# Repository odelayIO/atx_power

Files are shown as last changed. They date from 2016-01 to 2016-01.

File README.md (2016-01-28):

# 15 Port USB Power Supply using an ATX Power Supply
<br>
##### View on [gh-page](http://odelayio.github.io/atx_power/)

## Problem Statement
I’m continuously using all of my wall outlets to plug-in a USB wall wart power supply to use for all of my development boards (e.g. Raspberry Pi, Arduino, etc).  Over time I needed two 6 port power strips just to have enough outlets for the USB wall wart.  To address this issue, I designed a very simple 15 Power USB power supply using an ATX Power Supply.

## Introduction
This design is a passive USB power supply, meaning this design directly connects the ATX Power Supply +5DCV directly to the +5DCV pin of a USB connector.  I was considering adding a USB charging port controller and current limiting power switch such as the [TSP2511](http://www.ti.com/product/TPS2511).  But I wanted to keep this design simple.

## Parts List
| Name | Description | Distrubutor | Price | URL |
|---|---|---|---|---|
| USB Connector | 3 Stack USB | Mouser | $4.24 | [Link](http://www.mouser.com/Search/ProductDetail.aspx?R=33UBAR-TSN1Rvirtualkey63110000virtualkey706-33UBAR-TSN1) |
| Binding Post  | For the power supply | Sparkfun | $0.35 | [Link](https://www.sparkfun.com/products/9739) |
| Fuse Holder | Fuse Clip 5mm | Sparkfun | $0.25 | [Link](https://www.sparkfun.com/products/9773) |
| PCB | 15 Port USB | DirtyPCBs | $25 | [Link](https://dirtypcbs.com) |

## Assembly

<br>
<br>
######PCB Layout Design
<br>
PCB
---
<br>
######I had an old ATX Power Supply, so I just used this one.  This ATX Power Supply cost around $15 on Amazon.com
<br>
Step 1

---
<br>
######This is the ATX Power Supply with the cover off.  As you can see, there is room in this ATX Power Supply to fit the PCB.
<br>
Step 2

---
<br>
######This design doesn't use an ATX connect to save money on the BOM. So I trimmed the wires to the desired length.
<br>
Step 3

---
<br>
######Solder the ATX wires to the designated power rail of the PCB.  The voltage is labeled on the silkscreen.
<br>
Step 4

---
<br>
######Modified the ATX Power Supply, so the PCB can be mounted
<br>
Step 5

---
<br>
######Fully assembled 15 Port USB Power Supply.  
<br>
Step 6

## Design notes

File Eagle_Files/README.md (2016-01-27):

# Eagle 7.3.0 Design Files

## File Description

- ATX_Power_Supply.sch : Schematic File
- ATX_Power_Supply.brd : Layout File
- ATX_Power_Supply_Gerber274_Final_17NOV2015.zip : Submitted Gerber Files
  - Boards have been fab at http://dirtypcbs.com/

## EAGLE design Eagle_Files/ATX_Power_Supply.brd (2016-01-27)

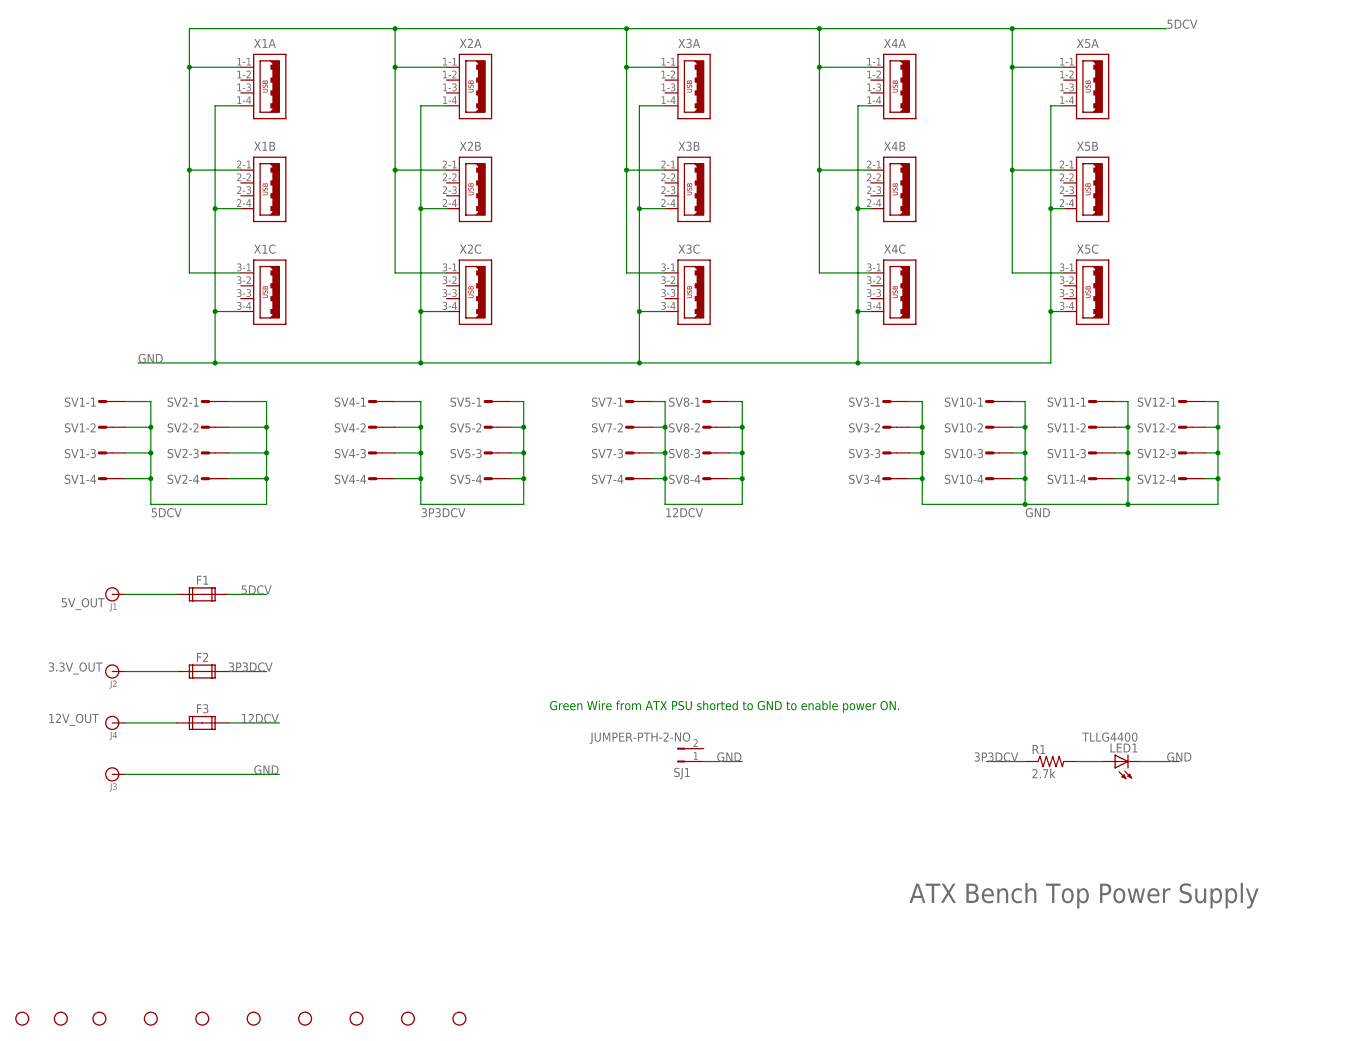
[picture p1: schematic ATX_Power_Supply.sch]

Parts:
F1, F2, F3: FUSE2P; FUSE1
J1, J2, J3, J4: BANANA_CONN
LED1: TLLG4400; LED3MM
R1: 2.7k; 0204/5
SJ1: JUMPER-PTH-2-NO; PTH-JUMPER-2-NO_NO_SILK
STANDOFF1, STANDOFF2, STANDOFF3, STANDOFF4, STANDOFF5, STANDOFF6, STANDOFF7, STANDOFF8, STANDOFF9, STANDOFF10: STAND-OFF
SV1, SV2, SV3, SV4, SV5, SV7, SV8, SV10, SV11, SV12: MT6-4
X1, X2, X3, X4, X5: USB_3PSHIELD-85-32003-00X-1; 85-32003-00X-1

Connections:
3.3V_OUT: F2.1A, J2.P$1
3P3DCV: F2.2A, R1.1, SV4.1, SV4.2, SV4.3, SV4.4, SV5.1, SV5.2, SV5.3, SV5.4
5DCV: F1.2A, SV1.1, SV1.2, SV1.3, SV1.4, SV2.1, SV2.2, SV2.3, SV2.4, X1.1-1 (1), X1.2-1 (1), X1.3-1 (1), X2.1-1 (1), X2.2-1 (1), X2.3-1 (1), X3.1-1 (1), X3.2-1 (1), X3.3-1 (1), X4.1-1 (1), X4.2-1 (1), X4.3-1 (1), X5.1-1 (1), X5.2-1 (1), X5.3-1 (1)
5V_OUT: F1.1A, J1.P$1
12DCV: F3.2A, SV7.1, SV7.2, SV7.3, SV7.4, SV8.1, SV8.2, SV8.3, SV8.4
12V_OUT: F3.1A, J4.P$1
GND: J3.P$1, LED1.K (C), SJ1.1, SV3.1, SV3.2, SV3.3, SV3.4, SV10.1, SV10.2, SV10.3, SV10.4, SV11.1, SV11.2, SV11.3, SV11.4, SV12.1, SV12.2, SV12.3, SV12.4, X1.1-4 (4), X1.2-4 (4), X1.3-4 (4), X2.1-4 (4), X2.2-4 (4), X2.3-4 (4), X3.1-4 (4), X3.2-4 (4), X3.3-4 (4), X4.1-4 (4), X4.2-4 (4), X4.3-4 (4), X5.1-4 (4), X5.2-4 (4), X5.3-4 (4)
unnamed: LED1.A, R1.2

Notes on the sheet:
Green Wire from ATX PSU shorted to GND to enable power ON.
ATX Bench Top Power Supply

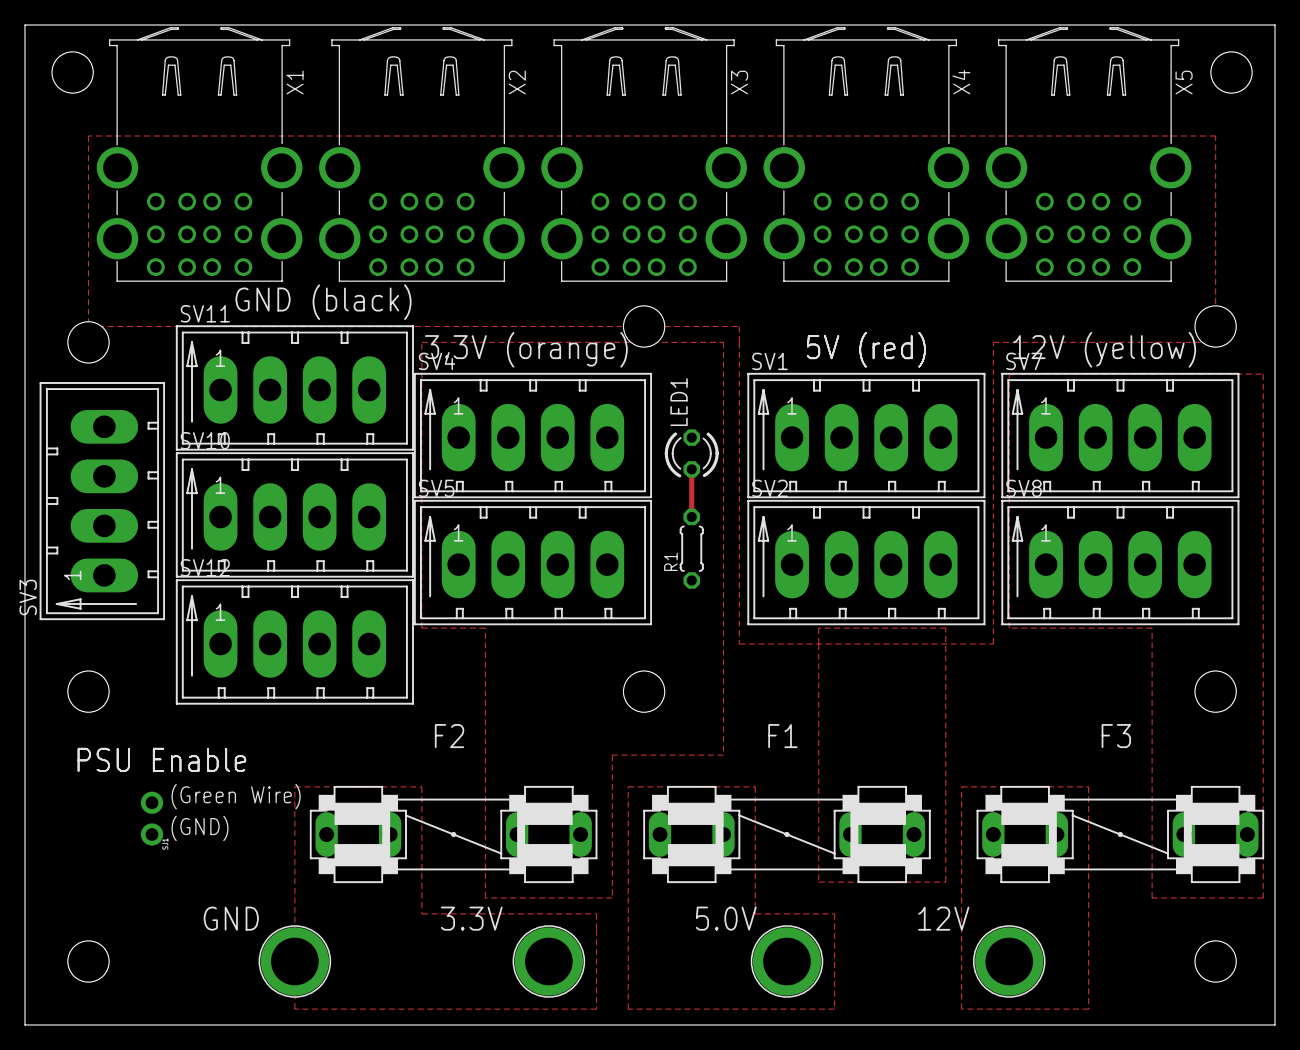
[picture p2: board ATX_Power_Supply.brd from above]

Board: 2 copper layers, 100.0 x 80.0 mm, 35 parts (0 on the bottom side), 8 nets.

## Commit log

2016-01-27 Adding Eagle Design Files
    [ATX_Power_Supply.brd, ATX_Power_Supply.sch]
2016-01-27 added pcb image

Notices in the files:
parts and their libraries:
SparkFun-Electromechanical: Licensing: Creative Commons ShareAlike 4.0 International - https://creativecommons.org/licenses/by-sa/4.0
